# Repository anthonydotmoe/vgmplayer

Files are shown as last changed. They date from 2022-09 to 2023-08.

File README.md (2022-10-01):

# RP2040 → YM2151 VGM Player

"It's a work in progress"

### Backstory

**2018**
This project started out using an ATMEGA328P and Arduino, but I found that it
was hard to write fast enough code to play songs at full speed. I then found
the STM32 series of microcontrollers; It was promising, but I really didn't like
the SDK or the HAL that was provided for these parts. After a few years, the
Raspberry Pi Foundation released the Raspberry Pi Pico. I bought the board
during its pre-order stage simply because it's a $5 microcontroller. This new
board, with their own RP2040 chip, has one key feature that I didn't know at the
time will make this project viable for me. The Programmable I/O (PIO).

**2022**
I finally got to looking at the datasheet for this board during DEFCON 2022,
where they used the RP2040 for their interactive badge. The PIO section caught
my eye, but I didn't look into it until a month later.

When I read the examples they had for driving WS2812 LED strips, I realized
what I could do with this extra power. I could easily get data to the chip on
time, every time; and have plenty of time for drawing a UI to a screen,
fetching data from an SD card over SPI, and in the future, emulating other
sound chips for game systems with AD/PCM and other chips.

### Hardware

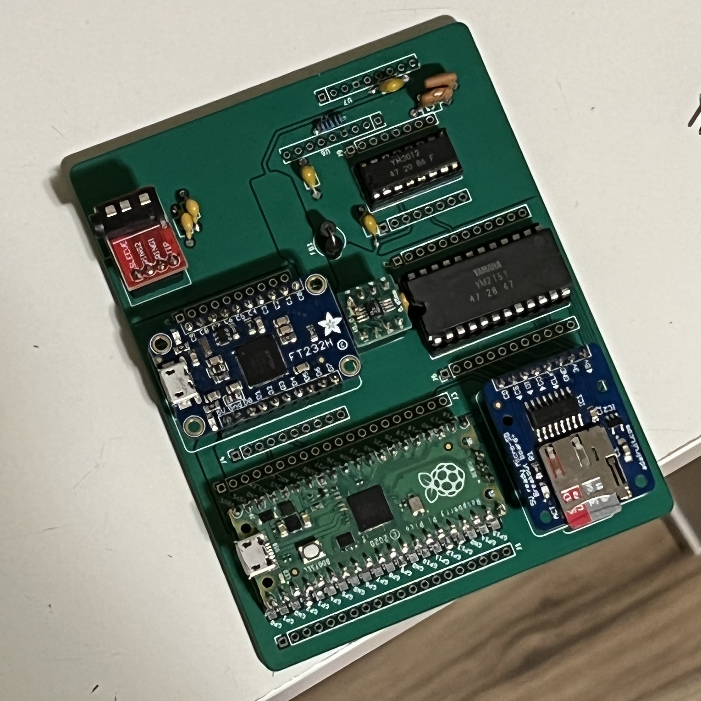
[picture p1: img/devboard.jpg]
YM2151 Pico Dev Board


I made this development board for the project.

GPIO 0-7 are connected to D0-D7 on the YM2151. GPIO 8-10 are connected to the
`A0`, `WR`, and `CS` pins. I'm using SPI to connect to the SD card, and an
LTC6903 programmable clock generator making the main clock for the YM2151.

The supporting circuitry for the YM2151 was ripped from the same place I got
the chip from, a Yamaha CX5 Music Computer.

### Software

*To be documented... and written*

### Thank You

Special thanks to:

- [ReimuNotMoe](https://github.com/ReimuNotMoe) for their work on
  [TinyVGM](https://github.com/SudoMaker/TinyVGM). This framework for digesting
  the `.vgm` files is really helpful for me.
- [Aidan Lawrence](https://github.com/AidanHockey5) for open-sourcing his
  [YM2151 music player](https://github.com/AidanHockey5/YM2151_VGM_STM32) which
  got me started in the ATMEGA328P days.

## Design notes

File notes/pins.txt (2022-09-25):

YM2151:		OPM FM sound generator
	D0-D7	Address/Data Bus (input/output)
	A0	Address/Data Select (input)
	_WR	Write (input)
	_RD	Read (input)
	_CS	Chip Select (input)
	_IC	Initial clear (input)
	_IRQ	Interrupt request (Output)
	ϕM	System clock (input)
	ϕ1	Clock for D/A (output)
--- Needs 12 inputs from processor (uC) ---

YM3012:		D/A Converter for YM2151
	ϕ1	System clock (input)
	SD	Serial data (input)
	SAM2	If high, section becomes CH2 sampling period (input)
	SAM1	If high, section becomes CH1 sampling period (input)
	_ICL	Initial Clear (If low, analog output becomes equal (S2 = S1 = 0, S0 = 1), regardless of SD signal) (input)
	SD	Serial data (input)
--- Needs  1 input  from processor (uC) ---

LTC6903:	SPI Programmable Oscillator
	SDI	Serial Data Input (input)
	SCK	Serial Port Clock (input)
	_SEN	Serial Port Enable (Chip Select) (Input)
	_CLK	Auxiliary Clock Output. Frequency set by serial port (output)
	CLK	Main Clock Output. Frequency set by serial port (output)
	OE	Asynchronous Output Enable. CLK and _CLK are set LOW when this pin is LOW. (input)

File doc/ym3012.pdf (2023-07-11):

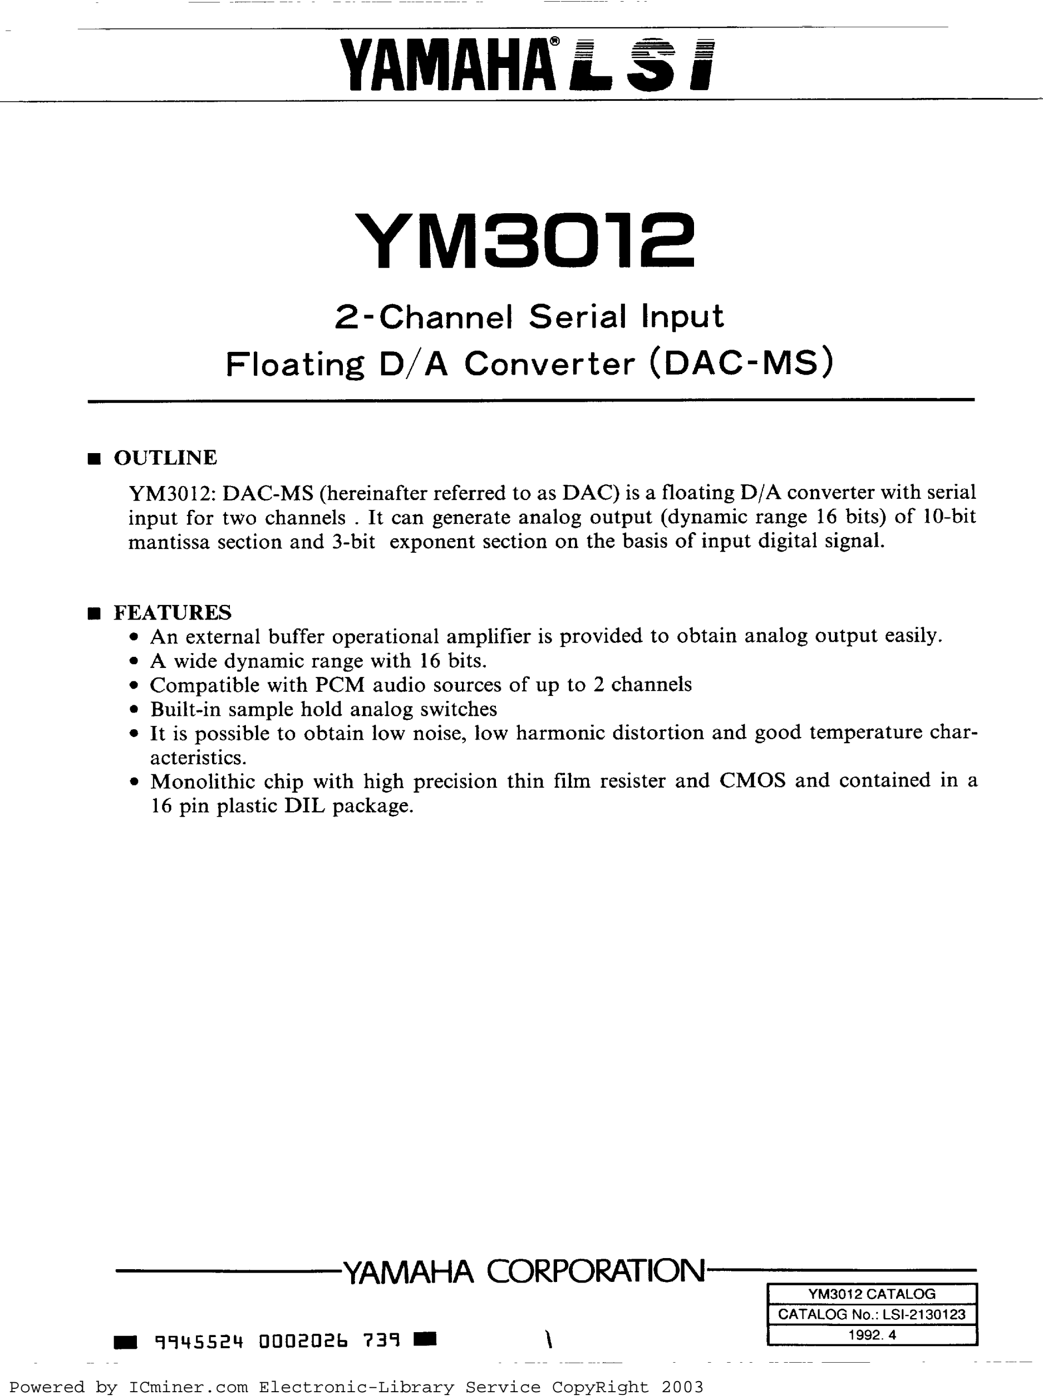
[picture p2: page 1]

Powered by ICminer.com Electronic-Library Service CopyRight 2003

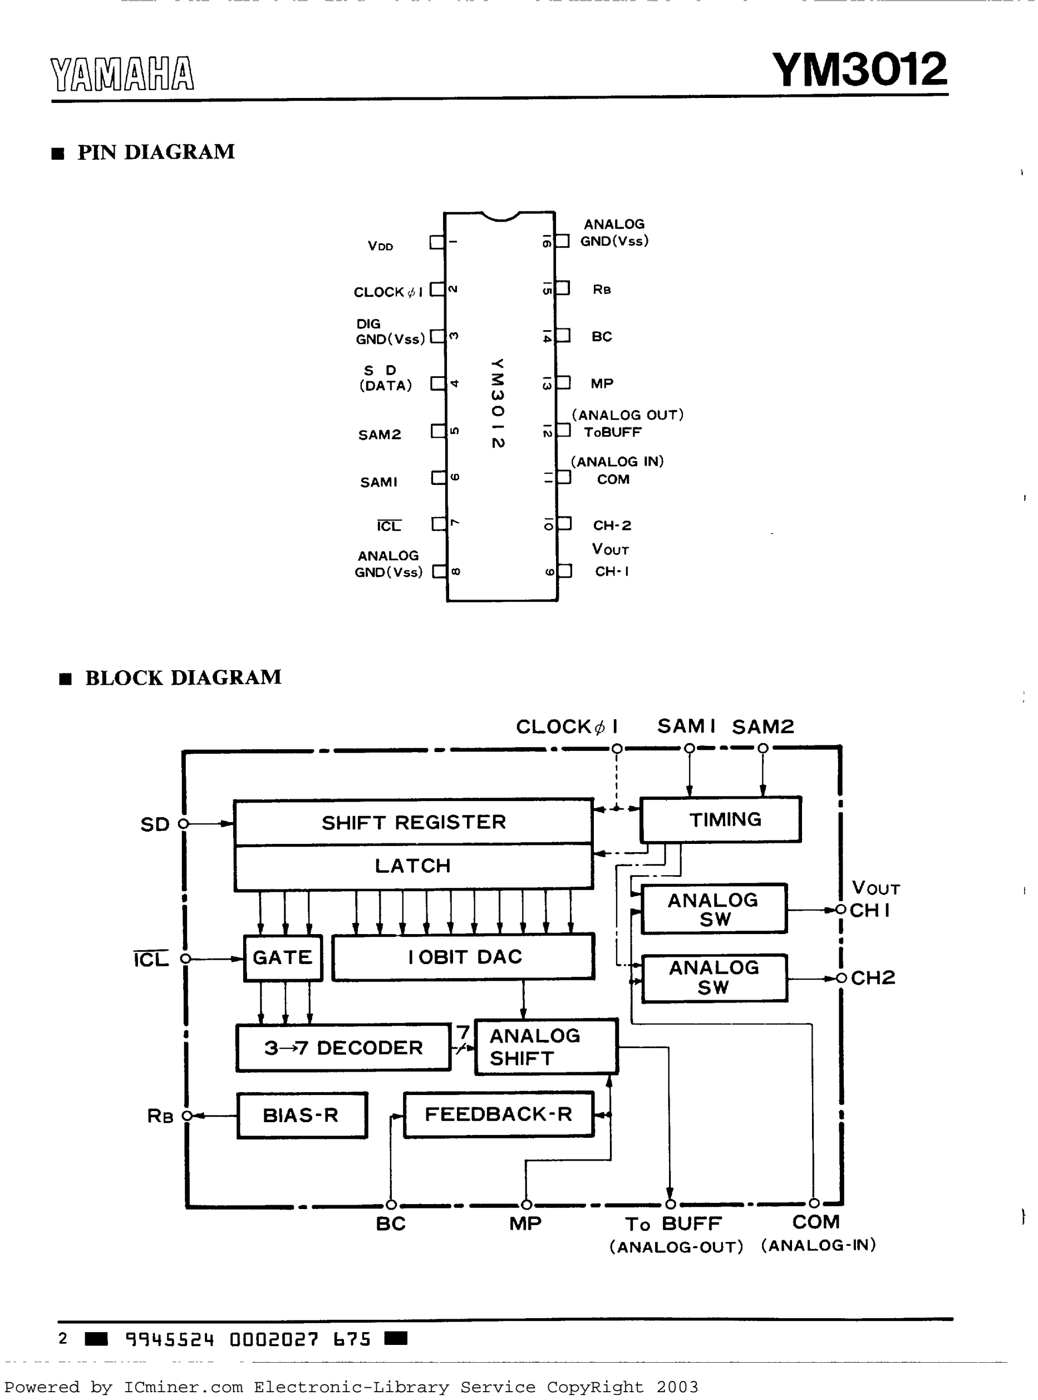
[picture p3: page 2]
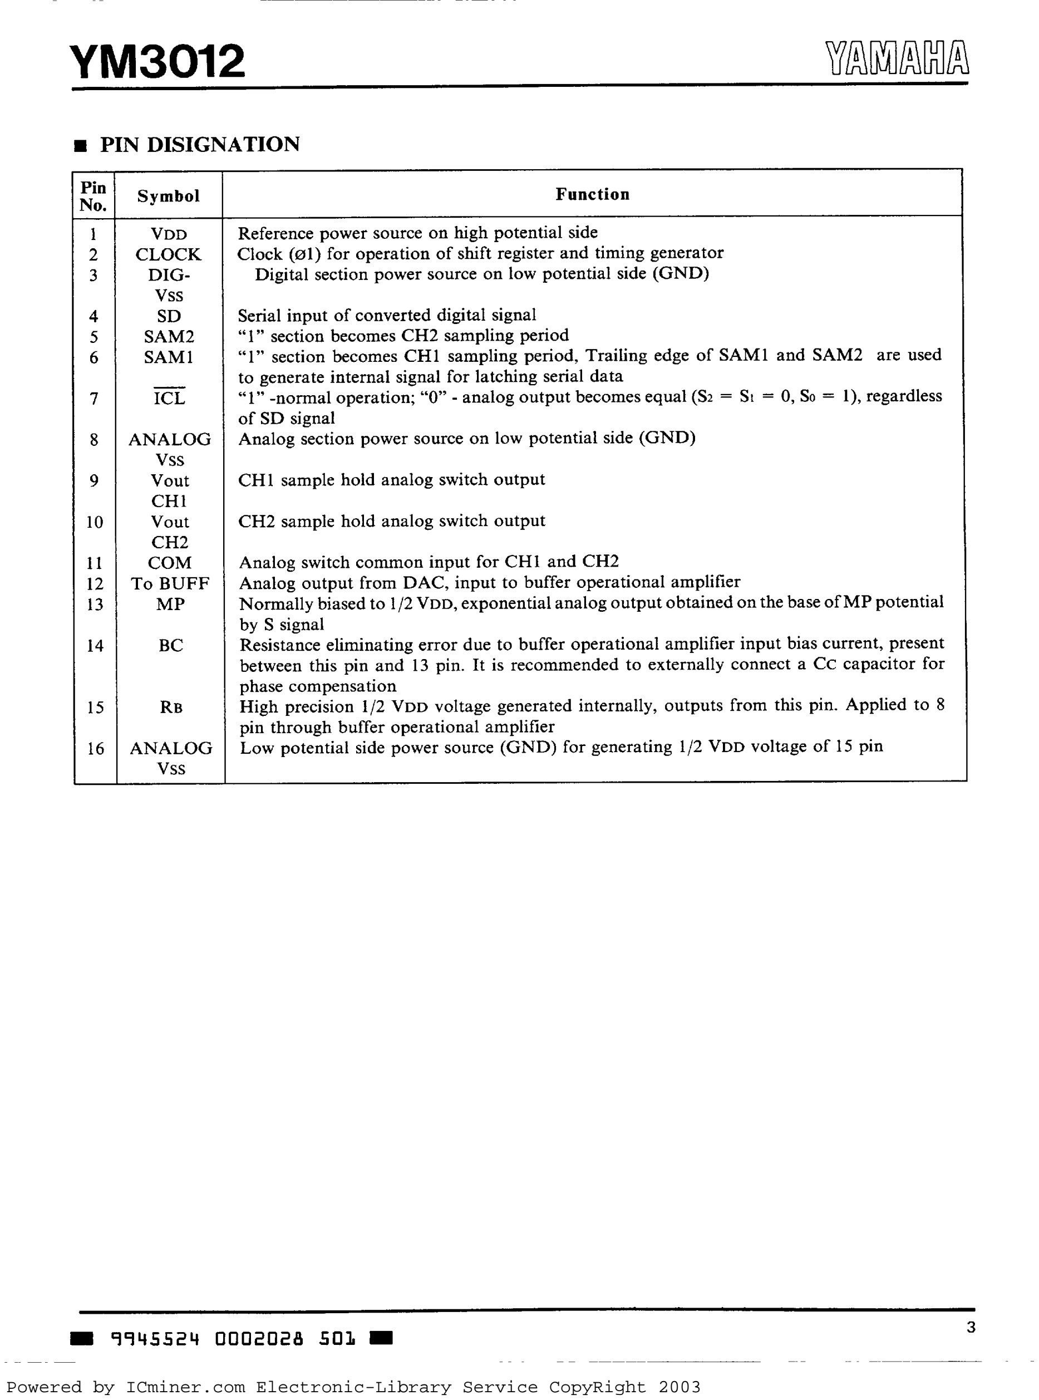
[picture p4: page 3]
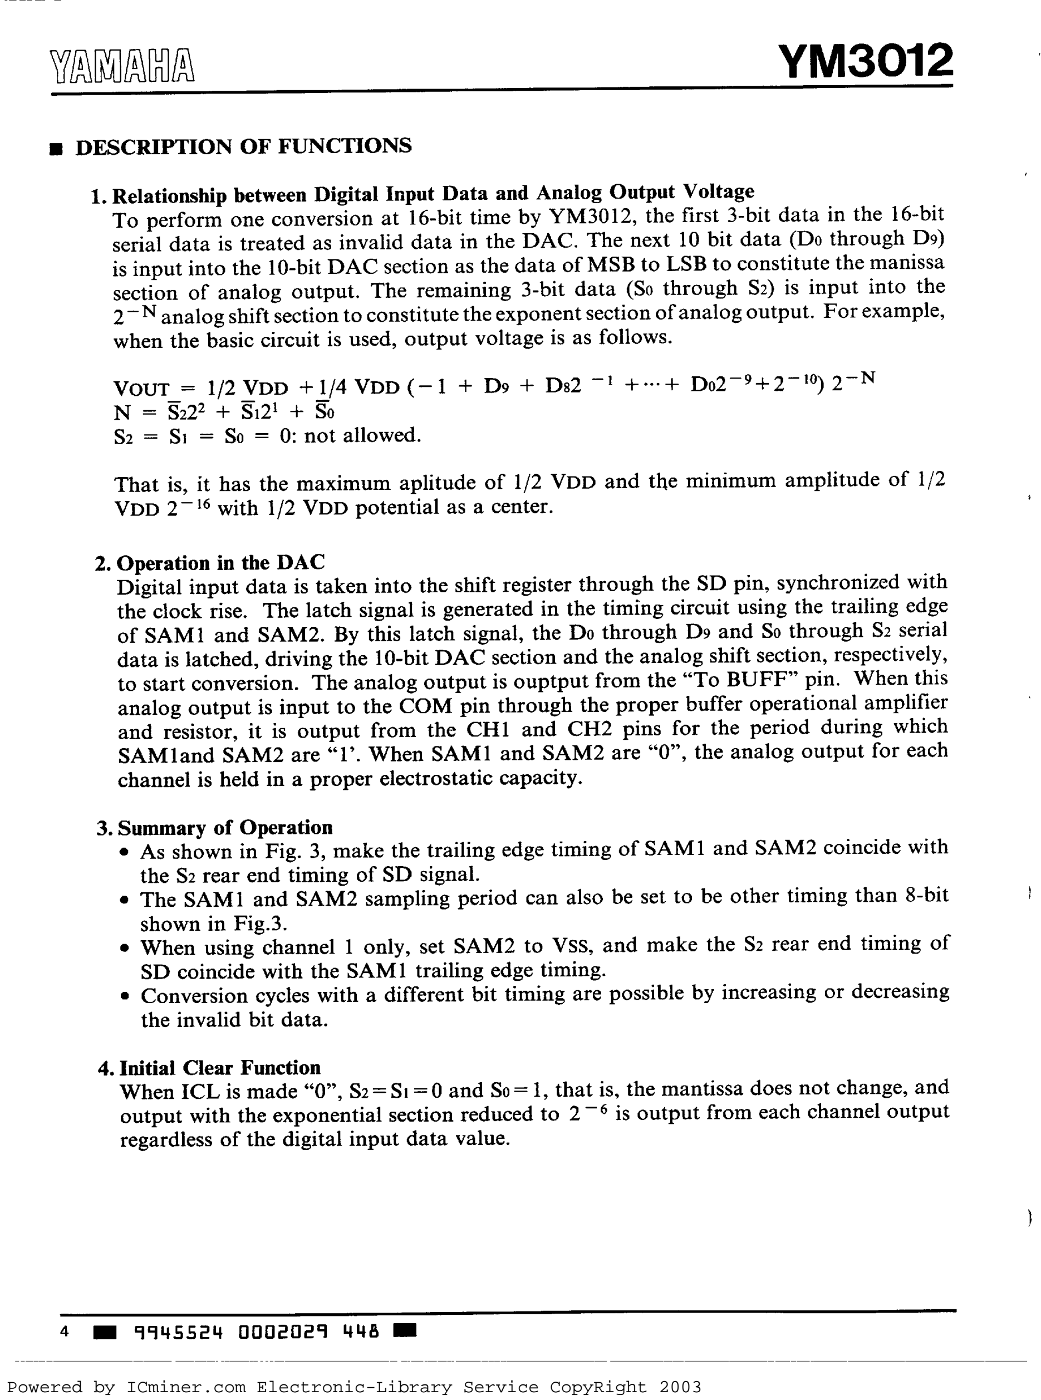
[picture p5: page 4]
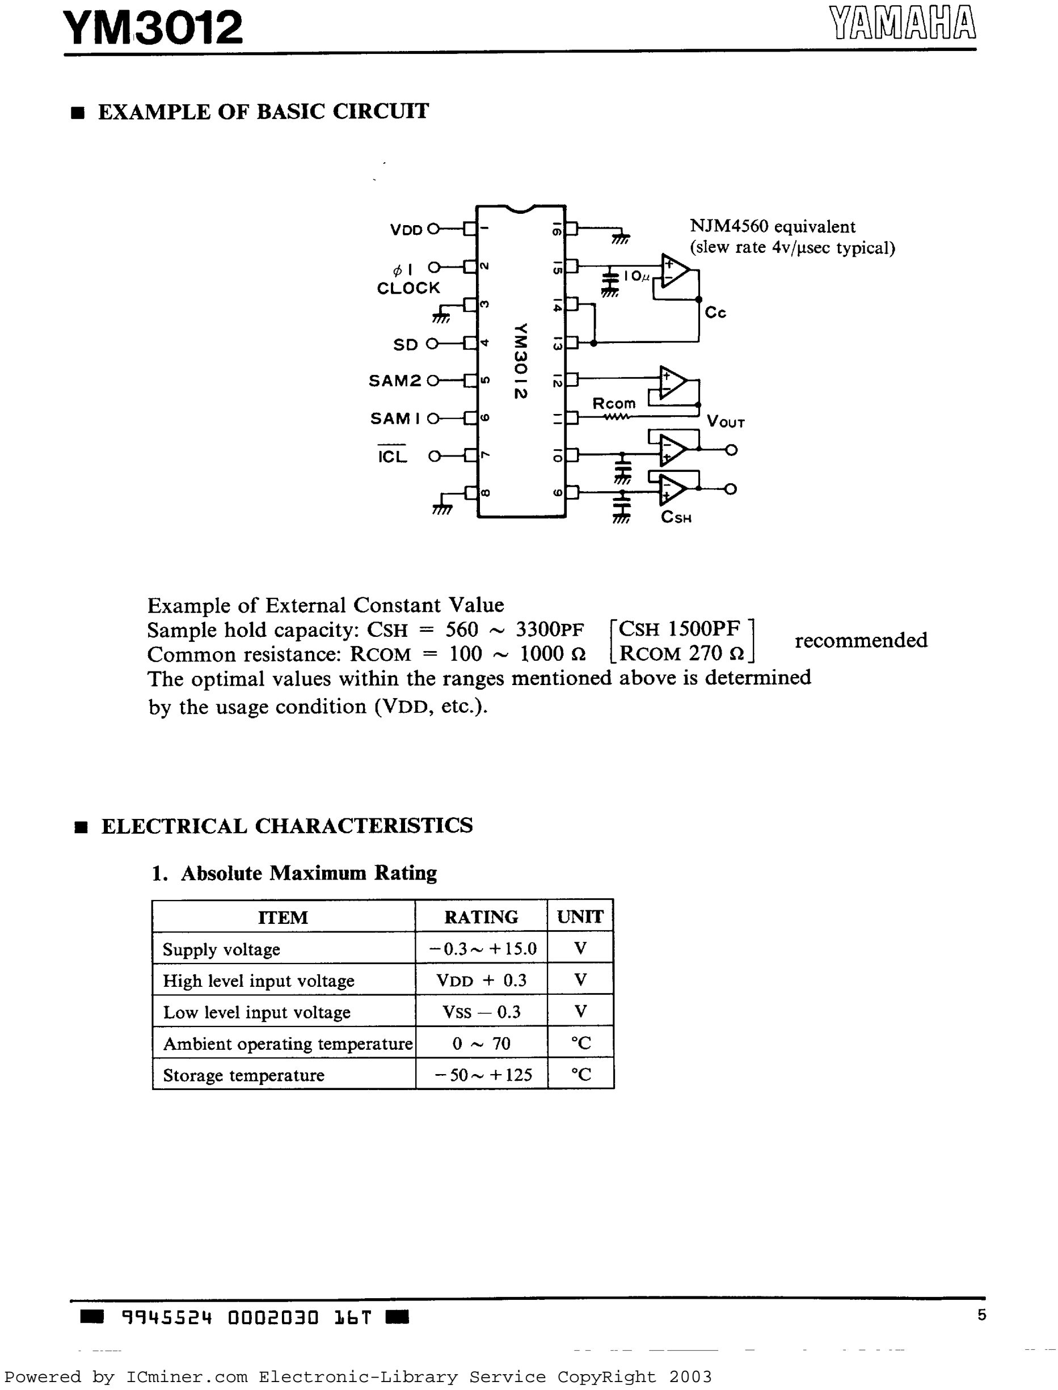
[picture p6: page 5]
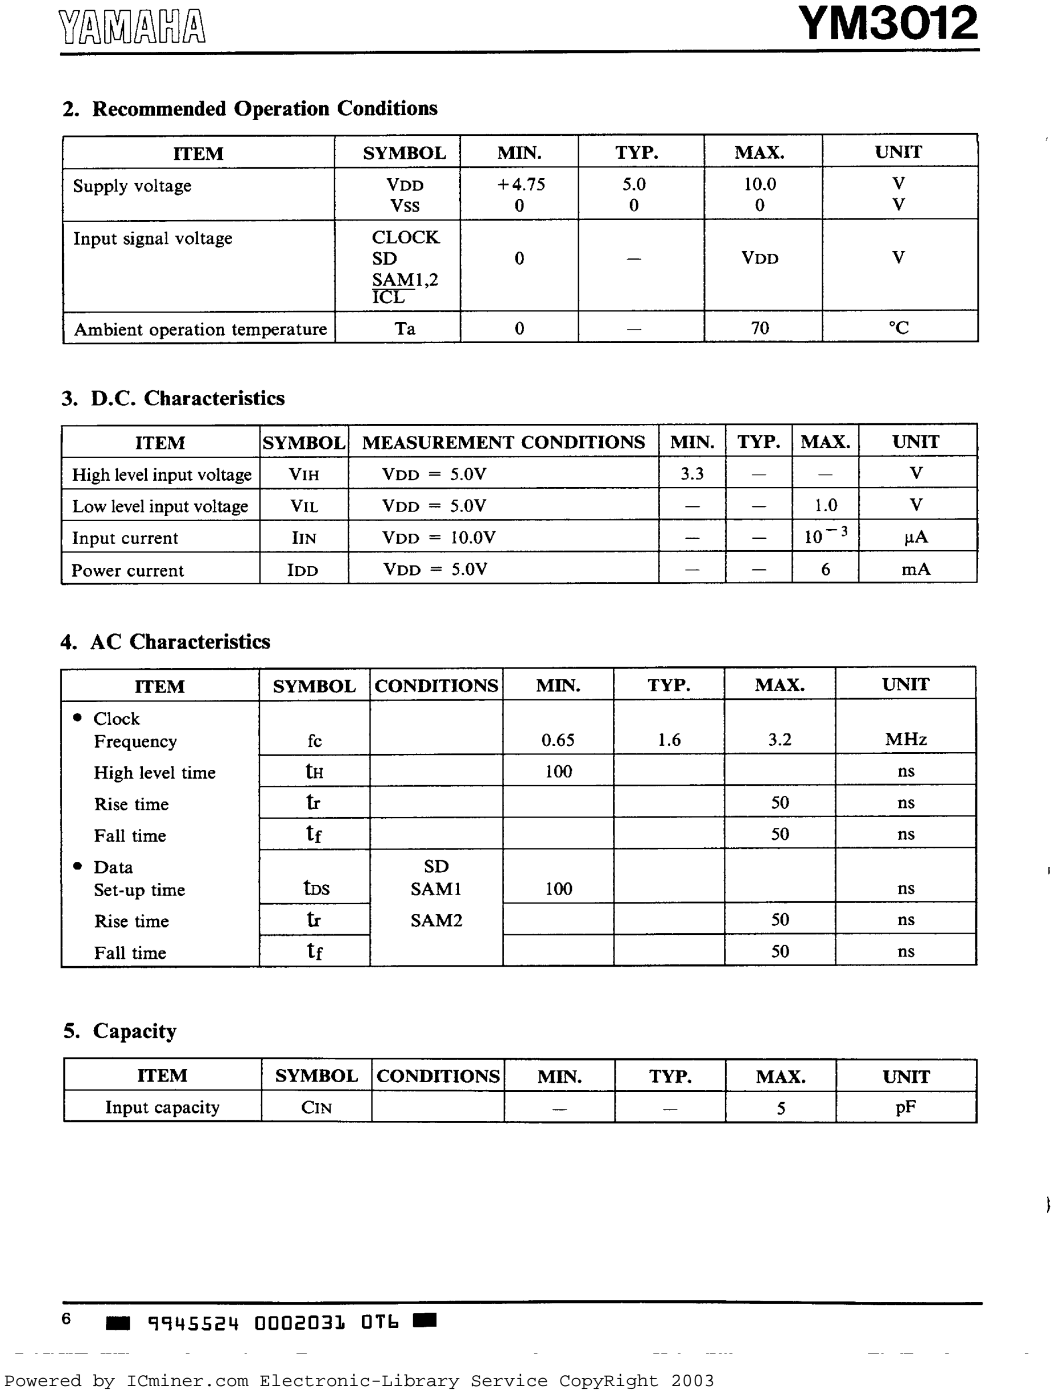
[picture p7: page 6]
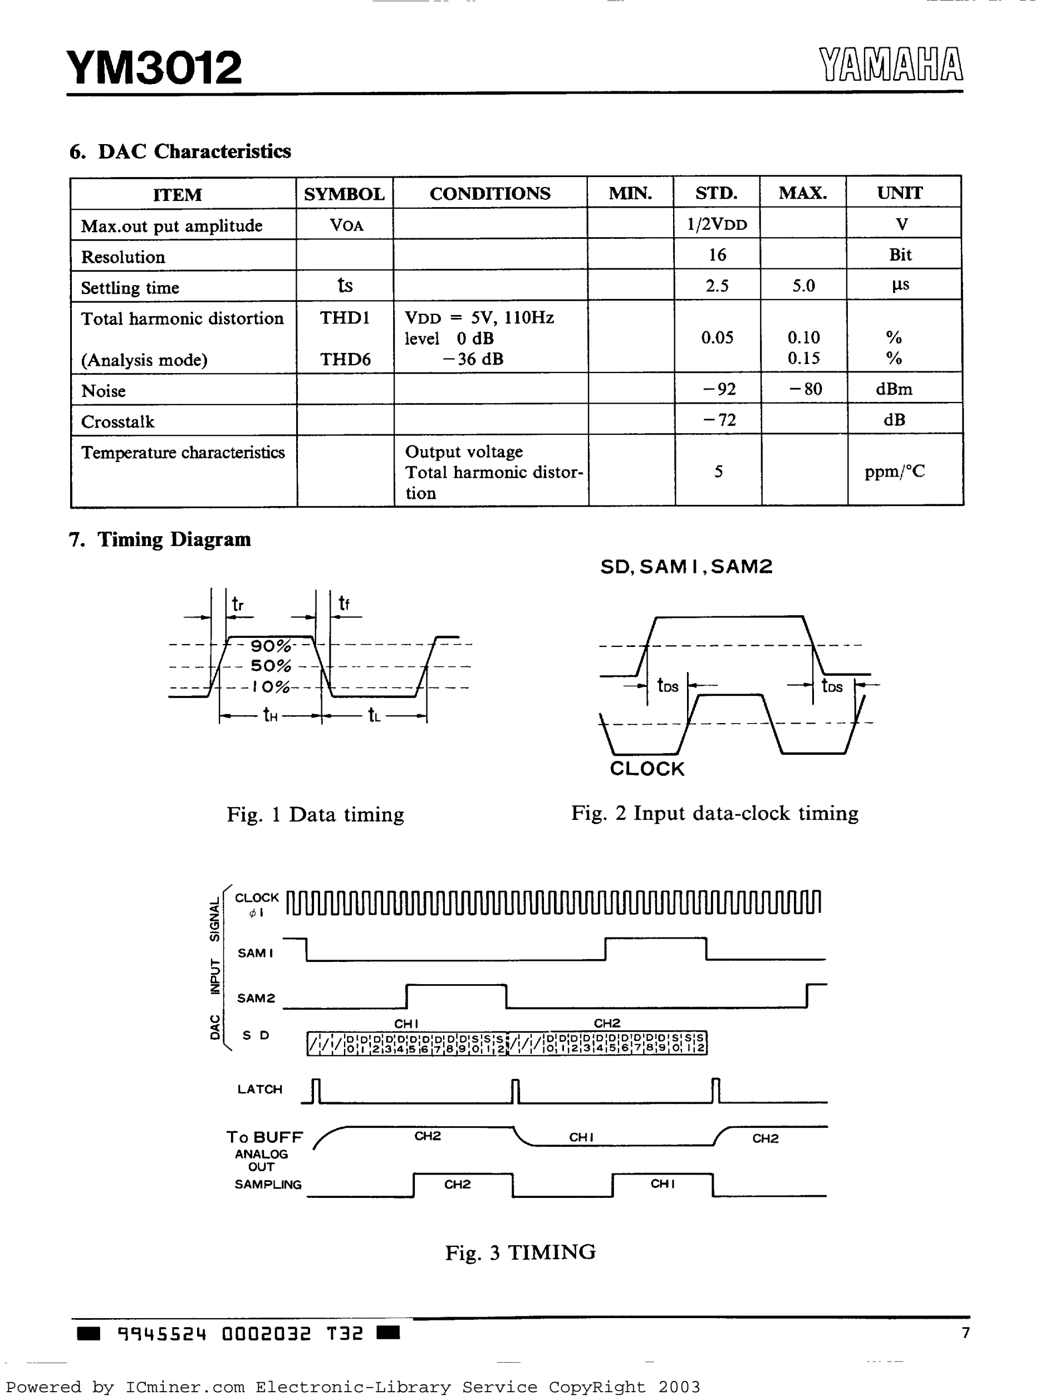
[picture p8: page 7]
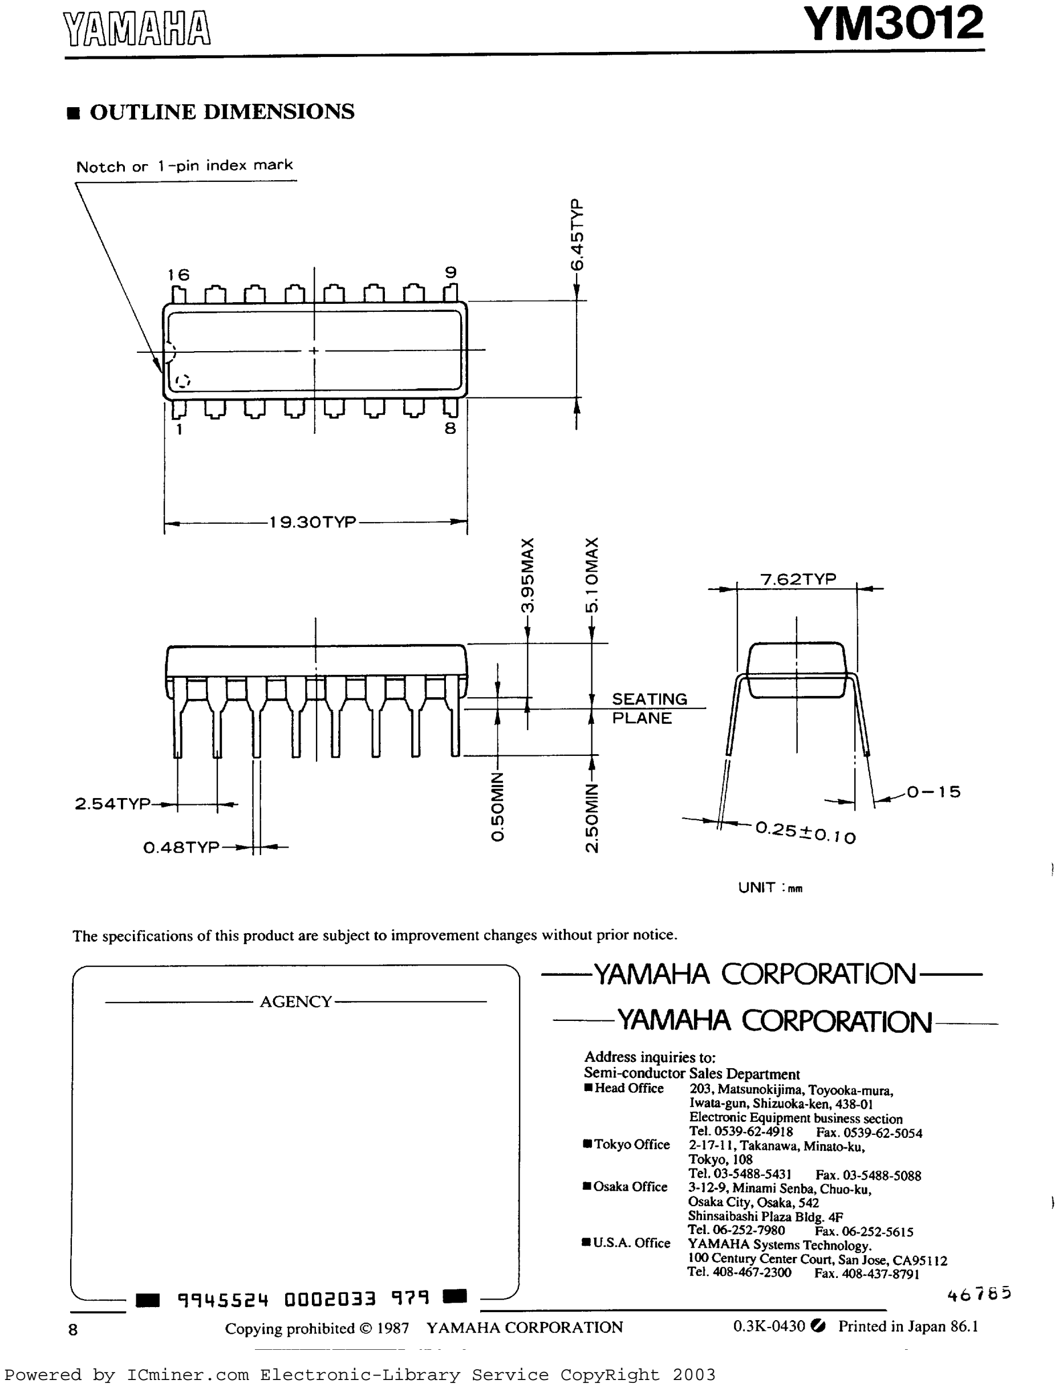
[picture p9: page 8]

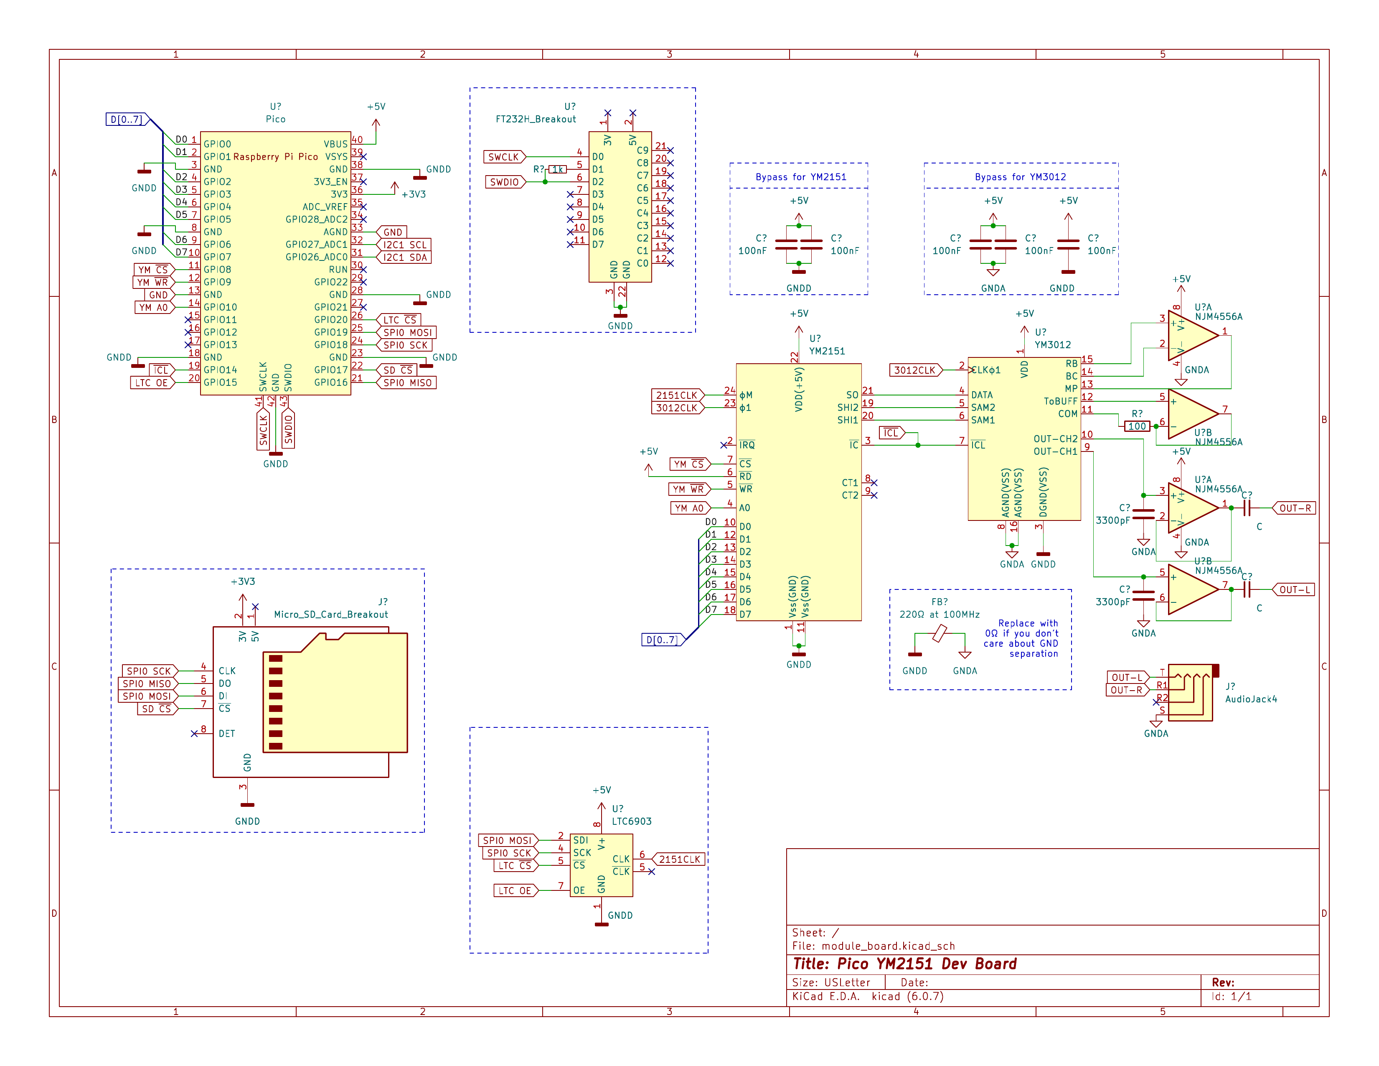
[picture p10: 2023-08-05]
hardware/module_board/module_board-1.png

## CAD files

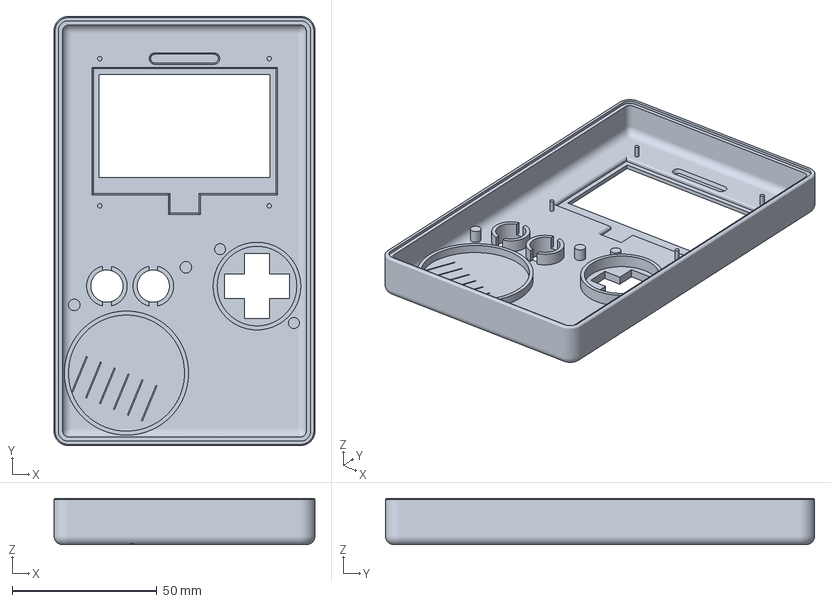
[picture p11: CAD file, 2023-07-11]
cad/case-PartFront.3mf
90.0 x 148.0 x 16.0 mm

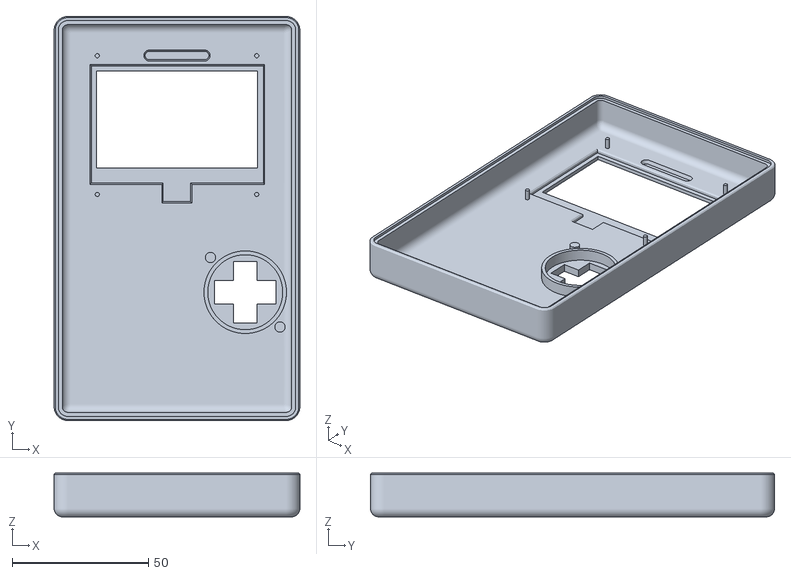
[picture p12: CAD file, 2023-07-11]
cad/case-Body.stl
90.0 x 148.0 x 16.0

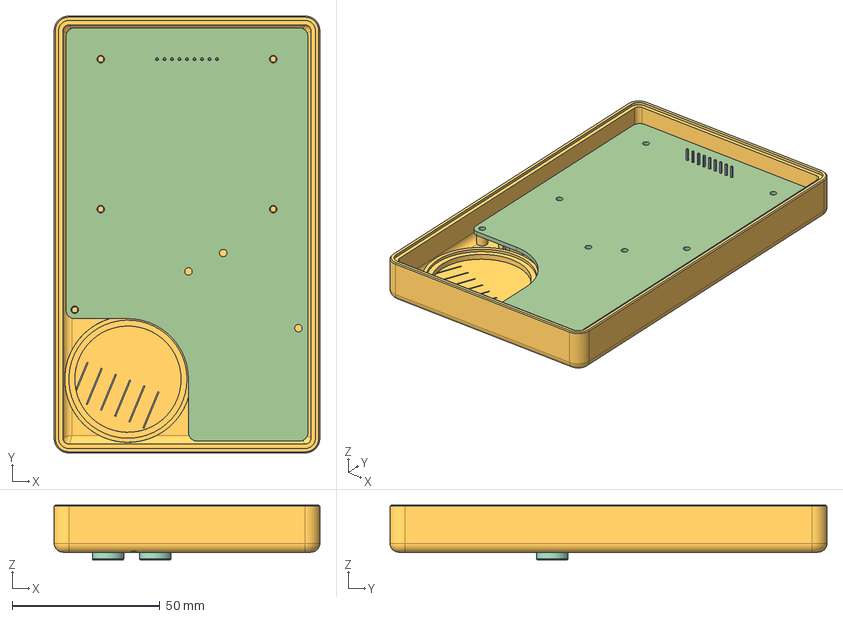
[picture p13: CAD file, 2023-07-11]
cad/case.FCStd
90.0 x 148.0 x 18.6 mm
Front
Screen
PCB
A-Button
B-Button

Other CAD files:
cad/case-PartFront.stl

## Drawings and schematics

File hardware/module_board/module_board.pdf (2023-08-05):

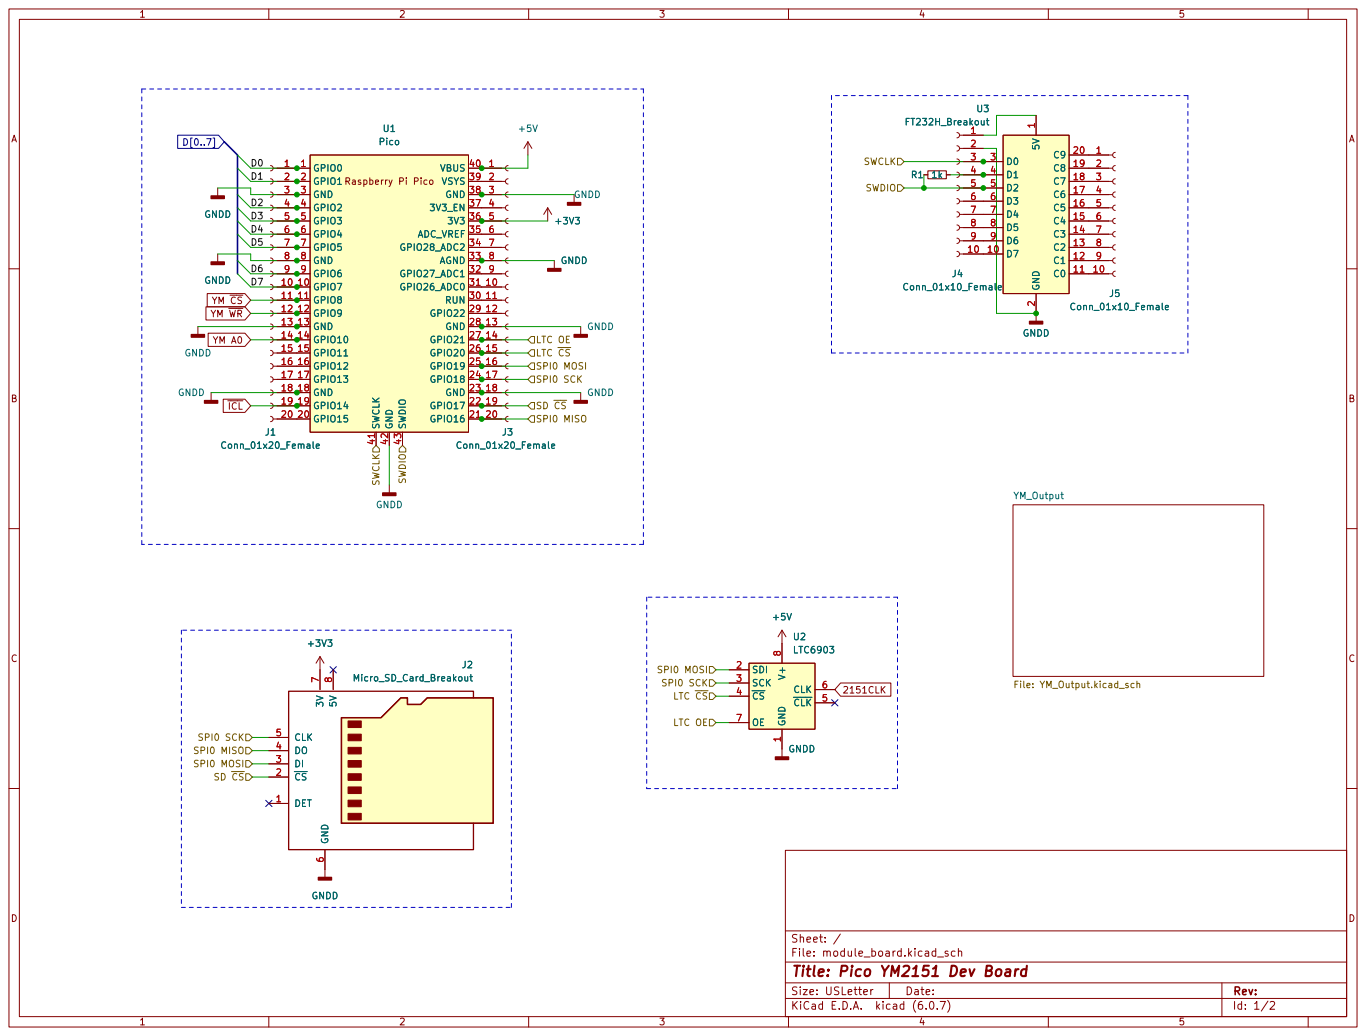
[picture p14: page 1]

SPI0 MOSI YM A0 YM ~{WR}

LTC OE
LTC ~{CS}
SD ~{CS} SPI0 MOSI SPI0 SCK

1 SDI 2 SCK 3 ~{CS} 4 ~{CLK} 5 CLK 6 OE 7 V+

SPI0 SCK
LTC ~{CS} LTC OE

SPI0 MOSI SD ~{CS} SPI0 SCK

File: module_board.kicad_sch Sheet: /
Id: 1/2 Title: Pico YM2151 Dev Board

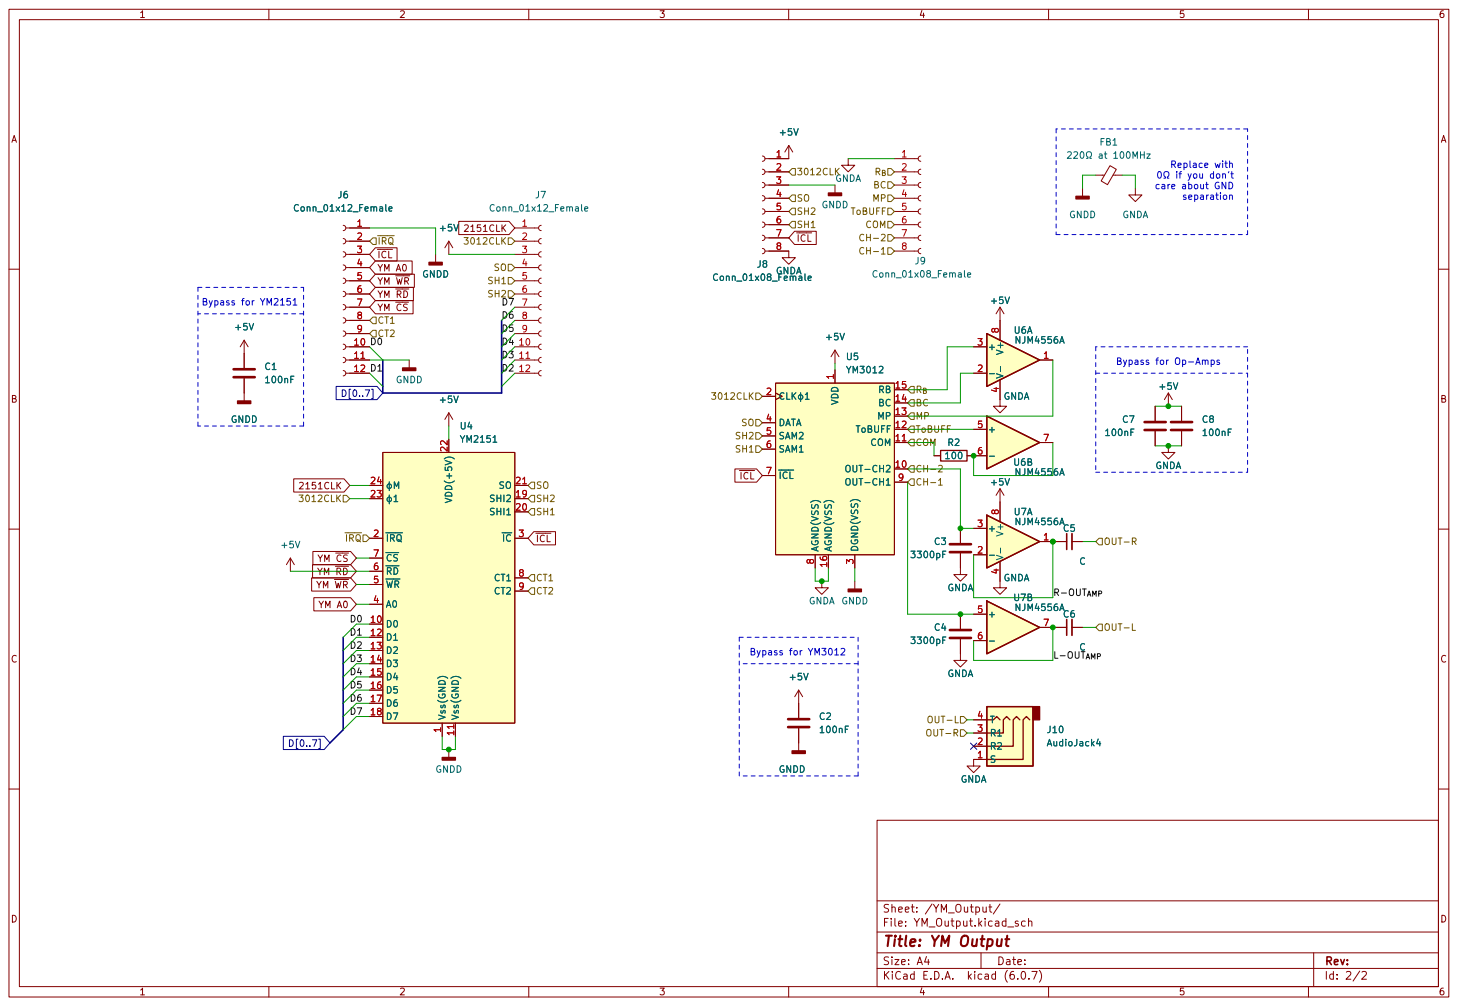
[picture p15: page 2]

Replace with
þÿ0© if you don't care about GND

File: YM_Output.kicad_sch
Id: 2/2 Title: YM Output

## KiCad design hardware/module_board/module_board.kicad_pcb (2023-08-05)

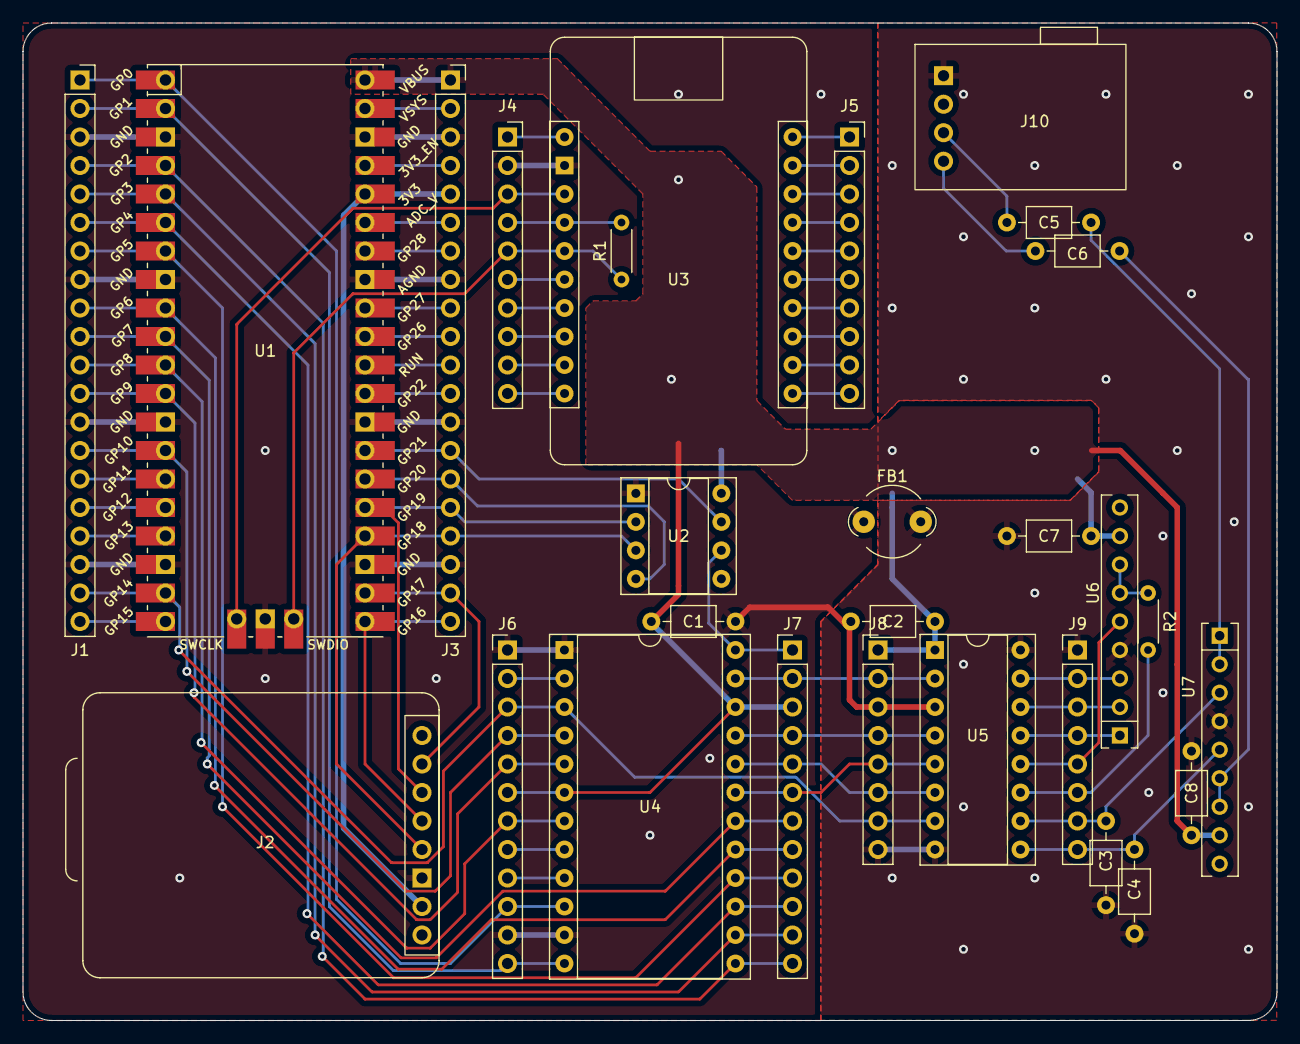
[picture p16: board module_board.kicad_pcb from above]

Board: 2 copper layers, 111.8 x 88.9 mm, 28 parts (0 on the bottom side), 73 nets.

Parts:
C1, C2, C7, C8: 100nF; C_Axial_L3.8mm_D2.6mm_P7.50mm_Horizontal
C3, C4: 3300pF; C_Axial_L3.8mm_D2.6mm_P7.50mm_Horizontal
C5, C6: C; C_Axial_L3.8mm_D2.6mm_P7.50mm_Horizontal
FB1: 220Ω at 100MHz; LairdTech_28C0236-0JW-10
J1, J3: Conn_01x20_Female; PinSocket_1x20_P2.54mm_Vertical
J2: Micro_SD_Card_Breakout; Adafruit_Micro-SD_Card_Breakout
J4, J5: Conn_01x10_Female; PinSocket_1x10_P2.54mm_Vertical
J6, J7: Conn_01x12_Female; PinHeader_1x12_P2.54mm_Vertical
J8, J9: Conn_01x08_Female; PinHeader_1x08_P2.54mm_Vertical
J10: AudioJack4
R1: 1k; R_Axial_DIN0204_L3.6mm_D1.6mm_P5.08mm_Horizontal
R2: 100; R_Axial_DIN0204_L3.6mm_D1.6mm_P5.08mm_Horizontal
U1: Pico; RPi_Pico_SMD_TH
U2: LTC6903; DIP-8_W7.62mm_Socket
U3: FT232H_Breakout; Adafruit_FT232H_Breakout
U4: YM2151; DIP-24_W15.24mm_Socket
U5: YM3012; DIP-16_W7.62mm_Socket
U6, U7: NJM4556A; SIP-9_22.3x3mm_P2.54mm

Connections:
2151CLK: J7.1, U2.6 (CLK), U4.24 (ϕM)
+3V3: J2.7 (3V), J3.5, U1.36 (3V3)
/LTC OE: J3.14, U1.27 (GPIO21), U2.7 (OE)
/LTC ~CS: J3.15, U1.26 (GPIO20), U2.4 (~CS)
/SD ~CS: J2.2 (~CS), J3.19, U1.22 (GPIO17)
/SPI0 MISO: J2.4 (DO), J3.20, U1.21 (GPIO16)
/SPI0 MOSI: J2.3 (DI), J3.16, U1.25 (GPIO19), U2.2 (SDI)
/SPI0 SCK: J2.5 (CLK), J3.17, U1.24 (GPIO18), U2.3 (SCK)
/SWCLK: J4.3, U1.41 (SWCLK), U3.3 (D0)
/SWDIO: J4.5, R1.1, U1.43 (SWDIO), U3.5 (D2)
/YM_Output/3012CLK: J7.2, J8.2, U4.23 (ϕ1), U5.2 (CLKϕ1)
/YM_Output/BC: J9.3, U5.14 (BC), U6.2 (-)
/YM_Output/CH-1: C4.1, J9.8, U5.9 (OUT-CH1), U7.5 (+)
/YM_Output/CH-2: C3.1, J9.7, U5.10 (OUT-CH2), U7.3 (+)
/YM_Output/COM: J9.6, R2.1, U5.11 (COM)
/YM_Output/CT1: J6.8, U4.8 (CT1)
/YM_Output/CT2: J6.9, U4.9 (CT2)
/YM_Output/L-OUT_{AMP}: C6.1, U7.6 (-), U7.7
/YM_Output/MP: J9.4, U5.13 (MP), U6.1
/YM_Output/OUT-L: C6.2, J10.4 (T)
/YM_Output/OUT-R: C5.2, J10.3 (R1)
/YM_Output/R-OUT_{AMP}: C5.1, U7.1, U7.2 (-)
/YM_Output/R_{B}: J9.2, U5.15 (RB), U6.3 (+)
/YM_Output/SH1: J7.5, J8.6, U4.20 (SHI1), U5.6 (SAM1)
/YM_Output/SH2: J7.6, J8.5, U4.19 (SHI2), U5.5 (SAM2)
/YM_Output/SO: J7.4, J8.4, U4.21 (SO), U5.4 (DATA)
/YM_Output/ToBUFF: J9.5, U5.12 (ToBUFF), U6.5 (+)
/YM_Output/~IRQ: J6.2, U4.2 (~IRQ)
D0: J1.1, J6.10, U1.1 (GPIO0), U4.10 (D0)
D1: J1.2, J6.12, U1.2 (GPIO1), U4.12 (D1)
D2: J1.4, J7.12, U1.4 (GPIO2), U4.13 (D2)
D3: J1.5, J7.11, U1.5 (GPIO3), U4.14 (D3)
D4: J1.6, J7.10, U1.6 (GPIO4), U4.15 (D4)
D5: J1.7, J7.9, U1.7 (GPIO5), U4.16 (D5)
D6: J1.9, J7.8, U1.9 (GPIO6), U4.17 (D6)
D7: J1.10, J7.7, U1.10 (GPIO7), U4.18 (D7)
GNDA: C3.2, C4.2, C7.2, C8.2, FB1.2, J8.8, J9.1, J10.1 (S), U5.8 (AGND(VSS)), U5.16 (AGND(VSS)), U6.4 (V-), U7.4 (V-)
GNDD: C1.1, C2.2, FB1.1, J1.3, J1.8, J1.13, J1.18, J2.6 (GND), J3.3, J3.8, J3.13, J3.18, J4.2, J6.1, J6.11, J8.3, U1.3 (GND), U1.8 (GND), U1.13 (GND), U1.18 (GND), U1.23 (GND), U1.28 (GND), U1.33 (AGND), U1.38 (GND), U1.42 (GND), U2.1 (GND), U3.2 (GND), U4.1 (Vss(GND)), U4.11 (Vss(GND)), U5.3 (DGND(VSS))
unnamed: J1.15, U1.15 (GPIO11)
unnamed: J1.16, U1.16 (GPIO12)
unnamed: J1.17, U1.17 (GPIO13)
unnamed: J1.20, U1.20 (GPIO15)
unnamed: J3.2, U1.39 (VSYS)
unnamed: J3.4, U1.37 (3V3_EN)
unnamed: J3.6, U1.35 (ADC_VREF)
unnamed: J3.7, U1.34 (GPIO28_ADC2)
unnamed: J3.9, U1.32 (GPIO27_ADC1)
unnamed: J3.10, U1.31 (GPIO26_ADC0)
unnamed: J3.11, U1.30 (RUN)
unnamed: J3.12, U1.29 (GPIO22)
unnamed: J4.1, U3.1 (5V)
unnamed: J4.4, R1.2, U3.4 (D1)
unnamed: J4.6, U3.6 (D3)
unnamed: J4.7, U3.7 (D4)
unnamed: J4.8, U3.8 (D5)
unnamed: J4.9, U3.9 (D6)
unnamed: J4.10, U3.10 (D7)
unnamed: J5.1, U3.20 (C9)
unnamed: J5.2, U3.19 (C8)
unnamed: J5.3, U3.18 (C7)
unnamed: J5.4, U3.17 (C6)
unnamed: J5.5, U3.16 (C5)
unnamed: J5.6, U3.15 (C4)
unnamed: J5.7, U3.14 (C3)
unnamed: J5.8, U3.13 (C2)
unnamed: J5.9, U3.12 (C1)
unnamed: J5.10, U3.11 (C0)
unnamed: R2.2, U6.6 (-), U6.7
YM A0: J1.14, J6.4, U1.14 (GPIO10), U4.4 (A0)
YM ~CS: J1.11, J6.7, U1.11 (GPIO8), U4.7 (~CS)
YM ~RD: C1.2, C2.1, C7.1, C8.1, J3.1, J6.6, J7.3, J8.1, U1.40 (VBUS), U2.8 (V+), U4.6 (~RD), U4.22 (VDD(+5V)), U5.1 (VDD), U6.8 (V+), U7.8 (V+)
YM ~WR: J1.12, J6.5, U1.12 (GPIO9), U4.5 (~WR)
~ICL: J1.19, J6.3, J8.7, U1.19 (GPIO14), U4.3 (~IC), U5.7 (~ICL)

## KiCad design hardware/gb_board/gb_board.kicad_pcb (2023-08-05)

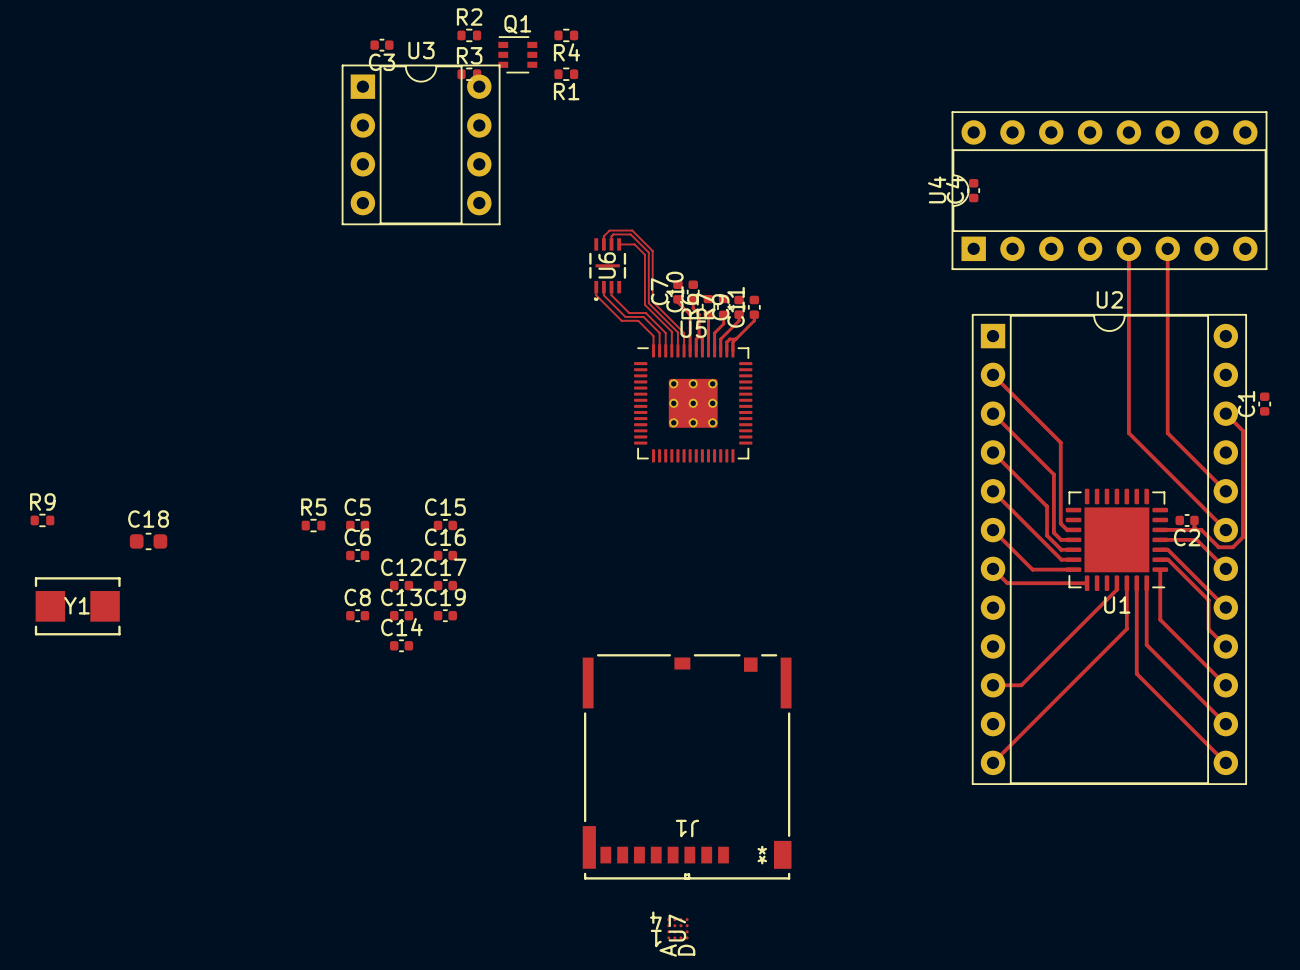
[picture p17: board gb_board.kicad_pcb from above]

Board: 2 copper layers, 37 parts (0 on the bottom side), 40 nets.

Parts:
C1, C2, C3, C4: 0.1uF; C_0402_1005Metric
C5, C6: 27p; C_0402_1005Metric
C7, C8, C9, C10, C11, C12, C13, C14, C15, C16, C17, C19: 100n; C_0402_1005Metric
C18: 10u; C_0603_1608Metric
J1: Micro_SD_Card_Det1; 503398-1892_MOL
Q1: BSS138PS; SOT-363_SC-70-6
R1, R2, R3, R4: 10k; R_0402_1005Metric
R5: 1k; R_0402_1005Metric
R6, R7: 27.4; R_0402_1005Metric
R9: DNF; R_0402_1005Metric
U1: MCP23017_ML; QFN-28-1EP_6x6mm_P0.65mm_EP4.25x4.25mm
U2: YM2151; DIP-24_W15.24mm_Socket
U3: LTC6903; DIP-8_W7.62mm_Socket
U4: YM3012; DIP-16_W7.62mm_Socket
U5: RP2040; RP2040-QFN-56
U6: W25Q16JVUXIQ; W25Q16JVUXIQ_WIN
U7: EMIF06-MSD04F3; FLIPCHIP16_STM
Y1: ABM3-12.000MHZ-D2Y-T; XTAL_ABM3_ABR

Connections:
+1V1: C7.1, C8.1, C9.1, U5.23 (DVDD), U5.45 (VREG_VOUT), U5.50 (DVDD)
+3V3: C3.1, C10.1, C11.1, C12.1, C13.1, C14.1, C15.1, C16.1, C17.1, C18.1, C19.1, J1.4 (VDD), Q1.2 (G1), Q1.5 (G2), R1.1, R2.1, R9.1, U3.8 (V+), U5.1 (IOVDD), U5.10 (IOVDD), U5.22 (IOVDD), U5.33 (IOVDD), U5.42 (IOVDD), U5.43 (ADC_AVDD), U5.44 (VREG_IN), U5.48 (USB_VDD), U5.49 (IOVDD), U6.8 (VCC)
+5V: C1.1, C2.1, C4.1, R3.1, R4.1, U1.5 (VDD), U2.22 (VDD(+5V)), U4.1 (VDD)
/RP2040/QSPI_D0: U5.53 (QSPI_SD0), U6.5 (DI(IO0))
/RP2040/QSPI_D1: U5.55 (QSPI_SD1), U6.2 (DO(IO1))
/RP2040/QSPI_D2: U5.54 (QSPI_SD2), U6.3 (IO2)
/RP2040/QSPI_D3: U5.51 (QSPI_SD3), U6.7 (IO3)
/RP2040/QSPI_F_~CS: R9.2, U5.56 (QSPI_SS), U6.1 (~CS)
/RP2040/QSPI_SCK: U5.52 (QSPI_SCLK), U6.6 (CLK)
/RP2040/RPUSB_N: R7.1, U5.46 (USB_DM)
/RP2040/RPUSB_P: R6.1, U5.47 (USB_DP)
/RP2040/SD_DET: J1.10 (DET_A), U5.36 (GPIO24)
/SAM1: U2.20 (SHI1), U4.6 (SAM1)
/SAM2: U2.19 (SHI2), U4.5 (SAM2)
/YM_SD: U2.21 (SO), U4.4 (DATA)
GNDA: C4.2, U4.8 (AGND(VSS)), U4.16 (AGND(VSS))
GNDD: C1.2, C2.2, C3.2, C5.1, C6.1, C7.2, C8.2, C9.2, C10.2, C11.2, C12.2, C13.2, C14.2, C15.2, C16.2, C17.2, C18.2, C19.2, J1.6 (VSS), J1.9 (DET_B), J1.11 (SHIELD), U1.6 (VSS), U1.11 (A0), U1.12 (A1), U1.13 (A2), U1.29 (EP), U2.1 (Vss(GND)), U2.11 (Vss(GND)), U3.1 (GND), U4.3 (DGND(VSS)), U6.4 (GND)
unnamed: C6.2, R5.1, Y1.2
unnamed: C5.2, U5.20 (XIN), Y1.1
unnamed: R5.2, U5.21 (XOUT)
SCL: Q1.4 (S2), R1.2, U5.7 (GPIO5)
SCL_5V: Q1.3 (D2), R3.2, U1.8 (SCK)
SDA: Q1.1 (S1), R2.2, U5.6 (GPIO4)
SDA_5V: Q1.6 (D1), R4.2, U1.9 (SDA)
YM_A0: U1.19 (GPA2), U2.4 (A0)
YM_D0: U1.25 (GPB0), U2.10 (D0)
YM_D1: U1.26 (GPB1), U2.12 (D1)
YM_D2: U1.27 (GPB2), U2.13 (D2)
YM_D3: U1.28 (GPB3), U2.14 (D3)
YM_D4: U1.1 (GPB4), U2.15 (D4)
YM_D5: U1.2 (GPB5), U2.16 (D5)
YM_D6: U1.3 (GPB6), U2.17 (D6)
YM_D7: U1.4 (GPB7), U2.18 (D7)
YM_DCLK: U2.23 (ϕ1), U4.2 (CLKϕ1)
YM_MCLK: U2.24 (ϕM), U3.6 (CLK)
YM_~CS: U1.22 (GPA5), U2.7 (~CS)
YM_~IC: U1.18 (GPA1), U2.3 (~IC), U4.7 (~ICL)
YM_~IRQ: U1.17 (GPA0), U2.2 (~IRQ)
YM_~RD: U1.21 (GPA4), U2.6 (~RD)
YM_~WR: U1.20 (GPA3), U2.5 (~WR)

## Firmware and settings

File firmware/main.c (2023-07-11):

#include <stdio.h>
#include <stdarg.h>
#include "pico/stdlib.h"
#include "sd_card.h"
#include "ff.h"

#include "lib/TinyVGM/TinyVGM.h"
#include "lib/ltc6903/ltc6903.h"

#include "vgmcb.h"
#include "ym2151.pio.h"

#define YM2151_DATA_BASE 0
#define YM2151_CTRL_BASE 8
#define YM2151_ICL_PIN   14
#define YM2151_ICL_DELAY 100

FRESULT init_sd_card();
void __attribute((noreturn)) die(const char *fmt, ...);

typedef enum {
	VGMPLAYER_PLAY,
	VGMPLAYER_PAUSE,
	VGMPLAYER_STOP
} VGMPLAYER_STATE;


int main(){
	FRESULT fr;
	FATFS fs;
	DIR root_dir;
	FILINFO filinfo;
	FIL fil;

	int ret;
	char buf;
	
	stdio_init_all();
	
	sleep_ms(500); // Wait for computer to catch up

	// Set up _ICL pin and silence the chips
	gpio_init(YM2151_ICL_PIN);
	gpio_set_dir(YM2151_ICL_PIN, GPIO_OUT);
	gpio_put(YM2151_ICL_PIN, 1);
	sleep_ms(YM2151_ICL_DELAY);
	gpio_put(YM2151_ICL_PIN, 0);
	sleep_ms(YM2151_ICL_DELAY);
	gpio_put(YM2151_ICL_PIN, 1);
	
	// Set up LTC6903
	printf("Initializing LTC6903\n");
	ltc_handle ltc_h = {
		.cs = 20,
		.oe = 21,
		.spi = spi0
	};
	ltc_initialize(&ltc_h);

	// Set up user pointer
	vgmcb_data_t vgmcb_data = {
		.fil = &fil,
		.state = VGMPLAYER_STOP,
		.ltc_h = &ltc_h
	};
	
	// Set up TinyVGM
	TinyVGMContext vgm_ctx = {
		.callback = {
			.header = vgmcb_header,
			.metadata = vgmcb_metadata,
			.data_block = vgmcb_datablock,
			
			.command = vgmcb_command,
			.read = vgmcb_read,
			.seek = vgmcb_seek,
		},
		
		.userp = &vgmcb_data
	};

	// Set up PIO SMs
	PIO pio = pio0;
	// Initialize the timer program
	uint pio_timer_program_offset = pio_add_program(pio, &ym2151_timer_program);
	uint pio_timer_program_sm = pio_claim_unused_sm(pio, true);
	init_ym2151_timer_program(pio, pio_timer_program_sm, pio_timer_program_offset);
	// Initialize the data program
	uint pio_data_program_offset = pio_add_program(pio, &ym2151_write_data_program);
	uint pio_data_program_sm = pio_claim_unused_sm(pio, true);
	init_ym2151_write_data_program(pio, pio_data_program_sm, pio_data_program_offset, 0, 8);

	// Share this data with the callback
	vgmcb_data.ym2151_data_pio = pio;
	vgmcb_data.ym2151_data_sm = pio_data_program_sm;

	// Initialize SD card
	fr = init_sd_card(&fs);
	if(fr != FR_OK) {
		die("Could not initialize the SD card");
	}

	fr = f_findfirst(&root_dir, &filinfo, "/", "*.vgm");
	if(fr != FR_OK) {
		die("searching for *.vgm, FatFS returned %d", fr);
	}

	while (*filinfo.fname) {
		// Open file
		fr = f_open(&fil, filinfo.fname, FA_READ);
		if (fr != FR_OK)
		{
			die("Could not open \"%s\", f_open returned %d", filinfo.fname, fr);
		}
		printf("Opened file: %s\n", filinfo.fname);

		// Parse header, get GD3 start, Data offset, determine if file can be played
		ret = tinyvgm_parse_header(&vgm_ctx);

		printf("tinyvgm_parse_header returned %d\n", ret);

		if (ret == TinyVGM_OK)
		{
			// Print Metadata
			if (get_gd3_offset_abs())
			{
				ret = tinyvgm_parse_metadata(&vgm_ctx, get_gd3_offset_abs());
				printf("tinyvgm_parse_metadata returned %d\n", ret);
			}
			
			// Play the tune
			if (get_data_offset_abs())
			{
				uint loop_count = 0;
				pio_sm_set_enabled(pio, pio_timer_program_sm, false);
				pio_sm_clear_fifos(pio, pio_data_program_sm);
				pio_sm_restart(pio, pio_data_program_sm);
				pio_sm_set_enabled(pio, pio_timer_program_sm, true);

				gpio_put(YM2151_ICL_PIN, 0); // Initial clear with low
				sleep_ms(YM2151_ICL_DELAY);
				gpio_put(YM2151_ICL_PIN, 1); // Set back to high
				sleep_ms(YM2151_ICL_DELAY);
				ret = tinyvgm_parse_commands(&vgm_ctx, get_data_offset_abs());
				/*
				while (!ret && loop_count < 1) {
					ret = tinyvgm_parse_commands(&vgm_ctx, get_loop_offset_abs());
					loop_count++;
				}
				*/
				printf("tinyvgm_parse_commands returned %d\n", ret);
			}
			printf("Playback finished\n");
		}
		sleep_ms(100);
		f_close(&fil);
		f_findnext(&root_dir, &filinfo);
	}

	f_unmount("0:");
	die("Out of vgm files");
}

FRESULT init_sd_card(FATFS *fs) {
	FRESULT fr;
	if(!sd_init_driver()) {
		return fr;
	}
	
	fr = f_mount(fs, "0:", 1);
	if(fr != FR_OK) {
		return fr;
	}
	printf("SD card initialized\n");
	return FR_OK;
}

void __attribute((noreturn)) die(const char *fmt, ...) {
	va_list args;

	printf("ERROR: ");
	va_start(args, fmt);
	vprintf(fmt, args);
	va_end(args);
	putchar('\n');
	while(true) {
	sleep_ms(1000);
	}
}

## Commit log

2022-09-28 Reconfigure no-OS-FatFS-SD-SPI-RPi-Pico submodule
2022-09-28 Replace copy of TinyVGM with real TinyVGM
    [main.c]
2022-09-28 first draft LTC6903 driver
2022-09-28 Mark .pio as Assembly
2022-09-28 Mark .pio files as Assembly
2022-09-30 Fix addr/data byte order
    [main.c]
2022-10-01 bump SPI to 25MHz
2023-07-11 project restructure
    [case-Body.stl, case-PartFront.3mf, case-PartFront.stl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]
2023-08-05 Add KiCAD sources
    [YM_Output.kicad_sch, gb_board.kicad_pcb, gb_board.kicad_sch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]
2026-05-14 disable FatFS LED blink
2026-05-14 fix 44.1kHz timer
